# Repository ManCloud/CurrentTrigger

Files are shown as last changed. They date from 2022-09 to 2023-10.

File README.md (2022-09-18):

# CurrentTrigger

## Description
This circuit will detect a current flowing through a current mirror and outputting a low-level signal once it reaces a certain threshold.
This is intended to work as a controller detection circuit for various consoles in combination with [DarthCloud](https://github.com/darthcloud)s [BlueRetro](https://github.com/darthcloud/BlueRetro) adapters for internal installation.

## Idle Currents per Console

| Controller | Idle Current |
|-|-|
| N64 (OEM) | 6 mA |
| DS2 (OEM) | 8 mA |
| GC (OEM) | 7.5 mA|
| MegaDrive (OEM)| <1 µA|
| NES (OEM) | <1 µA |

The circuit is designed to reliably output a low-level at a threshold of 300µA! Any controller consuming less in idle state is not detectable.

## Exampe Installation Points

- To be written

## Implemenatations using this approach
GameCube BlueRetro Internal Adapter by Collingall/Laser Bear Industries [Link](https://www.laserbear.net/products/gamecube-blue-retro-internal-adapter)

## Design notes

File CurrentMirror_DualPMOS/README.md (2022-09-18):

# CurrentTrigger - DualPMOS

## Pinout
J1.1 => VCC
J1.2 => Controller Supply

J2.1 => Controller Sense
J2.2 => GND

## Preview

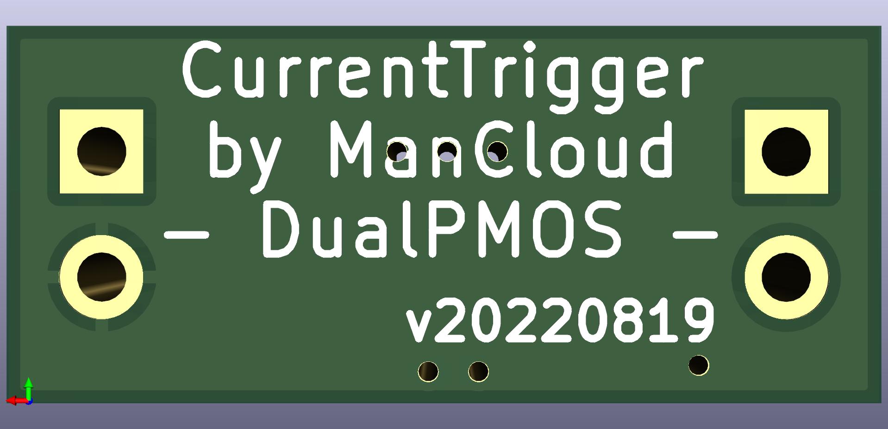
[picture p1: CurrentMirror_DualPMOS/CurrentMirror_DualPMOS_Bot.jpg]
PCB TOP

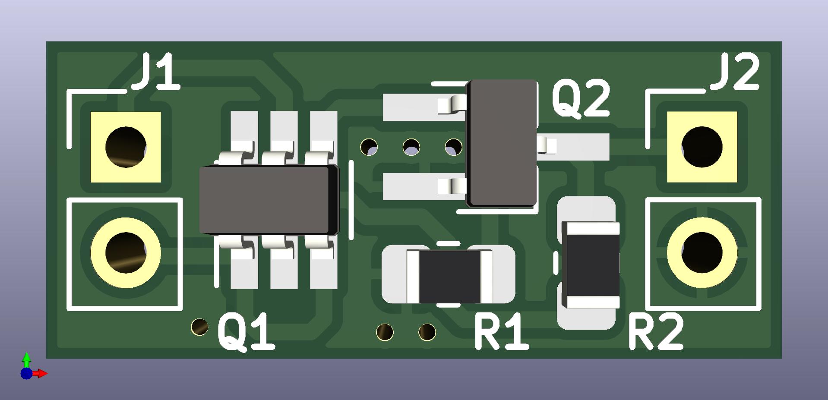
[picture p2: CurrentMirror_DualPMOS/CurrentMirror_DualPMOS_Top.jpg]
PCB BOT


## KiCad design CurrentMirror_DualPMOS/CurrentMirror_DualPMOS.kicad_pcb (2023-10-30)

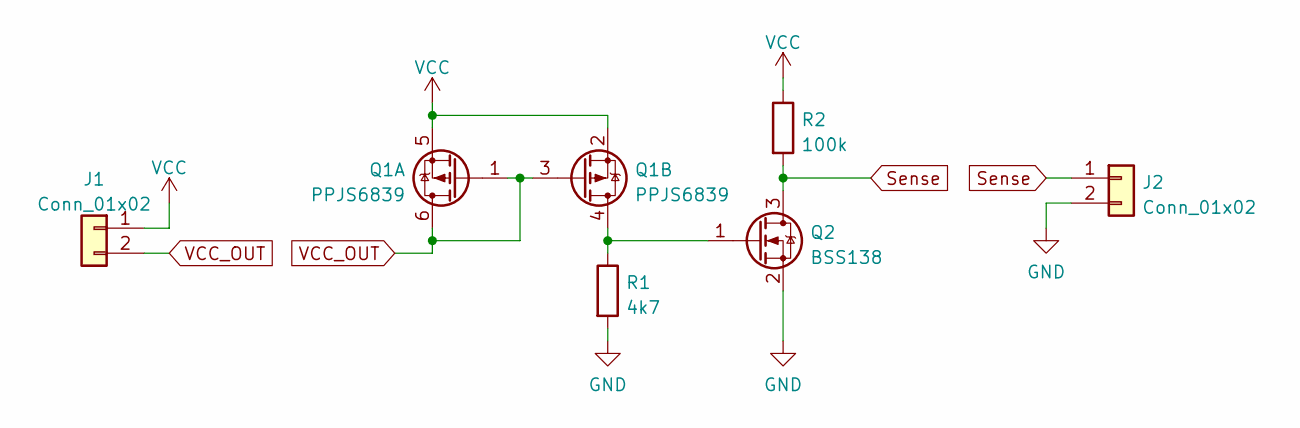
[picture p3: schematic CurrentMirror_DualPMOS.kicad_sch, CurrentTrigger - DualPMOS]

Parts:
J1, J2: Conn_01x02; PinHeader_1x02_P2.54mm_Vertical
Q1: PPJS6839; SOT-23-6_Handsoldering
Q2: BSS138; TSOT-23_HandSoldering
R1: 4k7; R_0805_2012Metric_Pad1.20x1.40mm_HandSolder
R2: 100k; R_0805_2012Metric_Pad1.20x1.40mm_HandSolder

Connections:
GND: J2.2, Q2.2 (S), R1.2
unnamed: Q1.4 (D), Q2.1 (G), R1.1
Sense: J2.1, Q2.3 (D), R2.2
VCC: J1.1, Q1.2 (S), Q1.5 (S), R2.1
VCC_OUT: J1.2, Q1.1 (G), Q1.3 (G), Q1.6 (D)

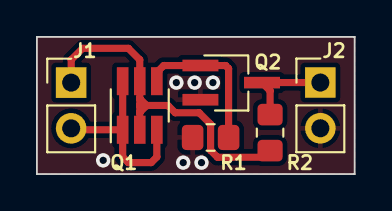
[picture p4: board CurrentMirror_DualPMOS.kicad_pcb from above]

Board: 2 copper layers, 17.7 x 7.6 mm, 6 parts (0 on the bottom side), 5 nets.

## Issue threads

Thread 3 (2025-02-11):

controller output voltage.

BevelTipDrip, 2025-02-11:
Maybe I'm missing something, but with 5v being input into the current mirror, only around 3v ends up coming out to the controller. Am I missing something with my implementation, or is this intended behavior? I'm using the PJS6839, and the circuit is identical to what's in the CAD files.

ManCloud, 2025-02-11:
It's not really intended behavior but is a functional limitation.

The output voltage is about V(GS) / U(BE) lower than the input voltage.

The "solution" for this is to either use a higher input voltage or to choose parts with a low switching voltage.

In my latest attempts I used PNP-BJT Transistors as they have a pretty consistent U(BE) of about 0.7-0.8V.

BevelTipDrip, 2025-02-11:
Thanks for the quick reply, glad I'm not missing. I was actually looking at dual PNP packages before I sent this. What do you think of these ICs with a shunt style setup? https://www.digikey.com/en/products/detail/texas-instruments/INA138NA-3K/765297 they're kind of pricey, but it should completely solve this problem.

BevelTipDrip, 2025-02-26:
I ended up using the Ti INA199B3DCKR, they go for around 50¢ each. The beauty of using one of these is your voltage drop is basically nothing, as you're using resistors in the mOhm range. The sensitivity can be tuned with the resistor to ensure whatever console it's being used on will properly detect the controllers.

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 My schematic here says INA199B2DCKR, they're the same chip with a different gain factor, I also ended up having to use a 300 mOhm resistor to ensure the gate of the fet biases on with newer lower power draw controllers like the retro fighters.
